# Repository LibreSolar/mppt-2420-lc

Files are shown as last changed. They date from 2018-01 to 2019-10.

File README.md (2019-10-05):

# MPPT Charger 20A

 Outdated design, development of new revision ongoing.

**Important:** As we are currently developing a new revision of this charge controller with several improvements, it is not recommended to rebuild this device anymore. Please see [this forum thread](https://talk.libre.solar/t/community-development-of-new-20a-mppt/121) and feel free to contribute your ideas.

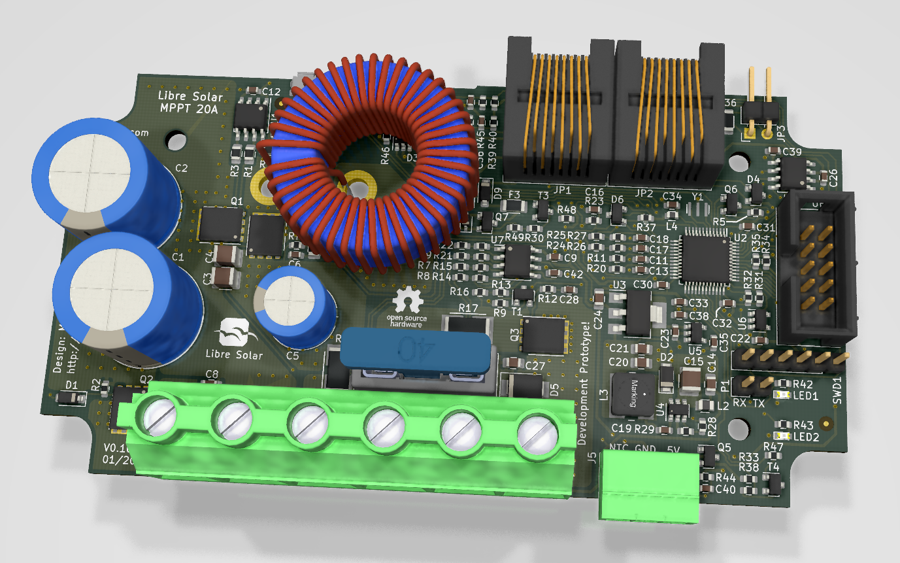
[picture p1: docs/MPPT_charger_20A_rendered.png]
Charge controller PCB


## Features:
- 20A MPPT charger (buck converter)
- 55V max PV input
- 12V or 24V battery output
- 32bit ARM MCU (STM32F072)
- CAN communication interface with CANopen standard RJ45 jacks (including 10V power supply)
- Expandable via Olimex Universal Extension Connector (UEXT) featuring I2C, Serial and SPI interface (e.g. used for display, WIFI communication, etc.)
- Compatible to Hammond Mfg 1591XXCFL housing
- 5V switchable signal output
- USB connector for programming etc.
- Can be used as boost converter with software change
- Suitable for Li-Ion batteries with BMS (even recharge after low voltage disconnect possible, as the charge controller increases the voltage automatically when enoug sunlight is available)

## Built-in protection:
- Overvoltage
- Undervoltage
- Overcurrent
- PV short circuit
- PV reverse polarity (for max. module open circuit voltage of around 40V)
- Battery reverse polarity (destructive, fuse is blown)

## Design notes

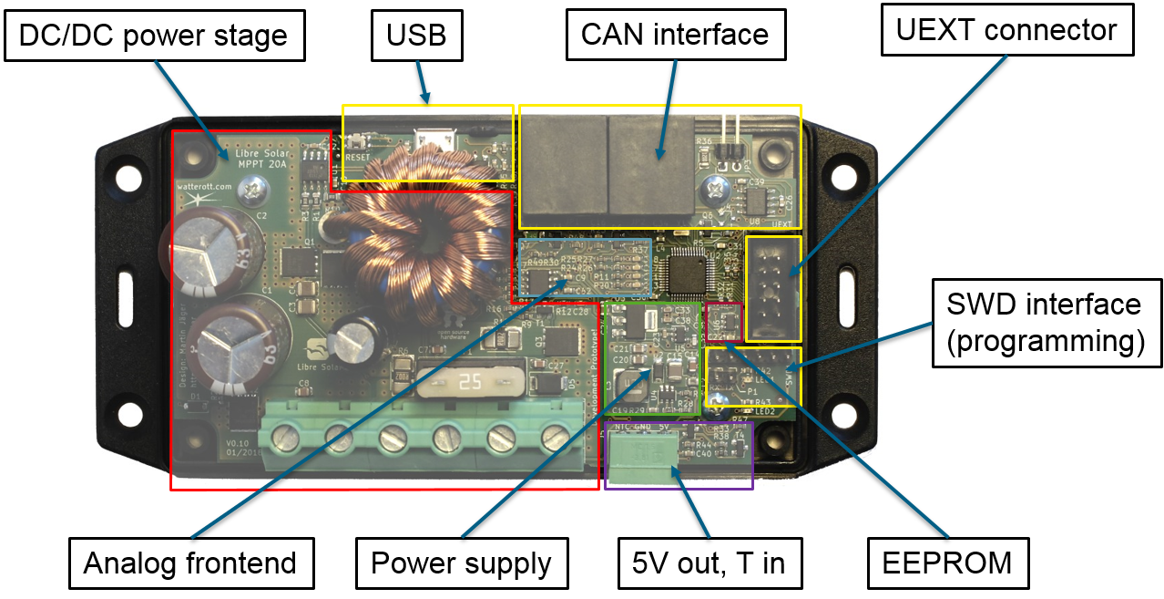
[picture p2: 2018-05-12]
docs/mppt_20a_hw_overview.png

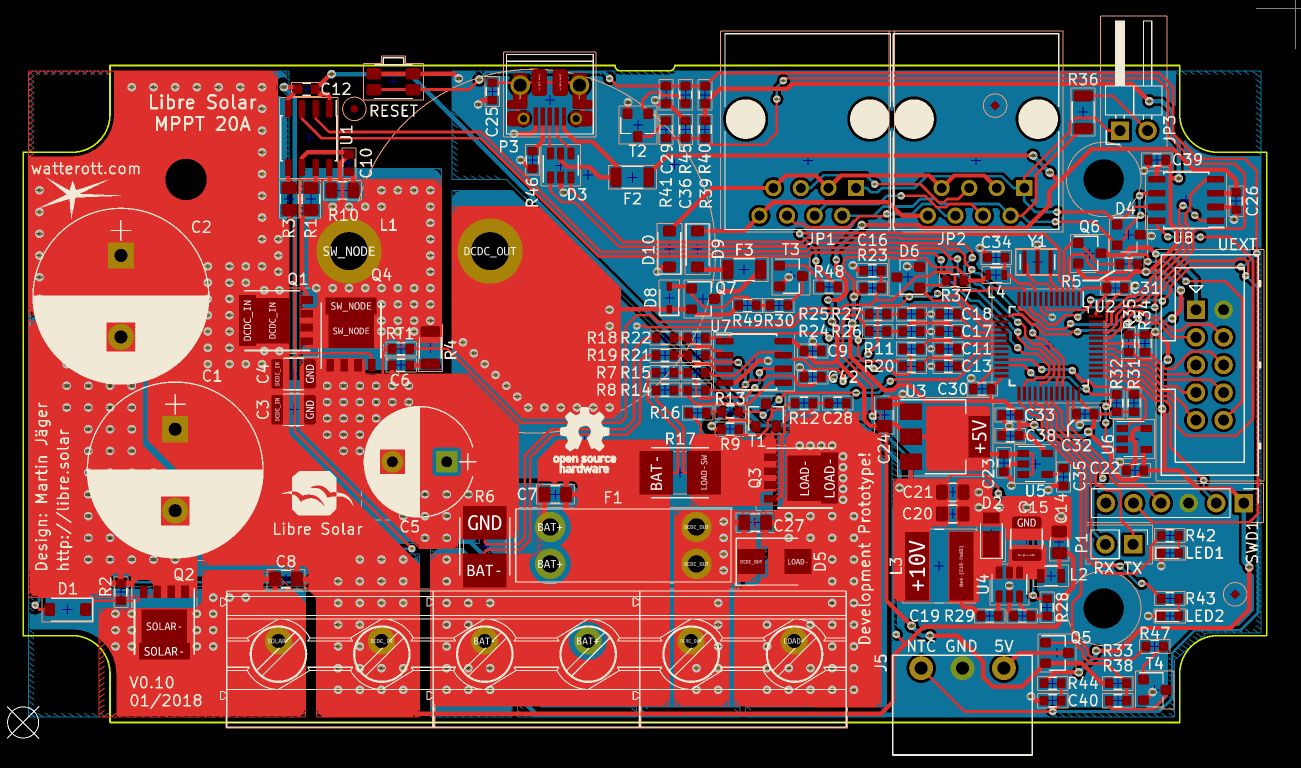
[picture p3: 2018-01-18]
docs/MPPT_charger_20A_top_view.png

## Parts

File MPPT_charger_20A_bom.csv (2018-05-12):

Component | Description | Part | References | Value | Footprint | Quantity Per PCB | Datasheet | Remarks | PartNumber | Manufacturer | Alternative | Supplier
1 | Polarised capacitor | CP_Small | C1 C2 | 1000u | CP_Radial_D16.0mm_P7.50mm | 2 |  | 63V, 2.74A, 16x25 | EKYB630ELL102ML25S | United Chemi-Con
2 | Unpolarized capacitor | C | C9 C10 C16 C19 C22 C25 C26 C29 C30 C31 C32 C34 C39 C40 C42 | 100n | C_0603_1608 | 15 |  |  | GRM188R71H104KA93D | Murata
3 | Unpolarized capacitor | C | C35 | 100p | C_0603_1608 | 1 |  |  | GRM1885C2A101JA01D | Murata
4 | Unpolarized capacitor | C | C11 C13 C17 C18 C28 | 10n | C_0603_1608 | 5 |  |  | GRM188R71H103KA01J | Murata
5 | Unpolarized capacitor | C | C20 C21 C24 | 10u | C_0805_2012 | 3 |  | 25V | GRM21BR61E106KA73L | Murata
6 | Unpolarized capacitor | C | C6 | 1n | C_0603_1608 | 1 |  | NP0/C0G | GRM1885C2A102JA01D | Murata
7 | Unpolarized capacitor | C | C7 C8 C14 C27 | 1u | C_0805_2012 | 4 |  | 100V, X7S | GRJ21BC72A105KE11L | Murata
8 | Unpolarized capacitor | C | C12 C23 C33 C36 C38 | 2.2u | C_0603_1608 | 5 |  | 25V, X5R | GRM188R61E225KA12D | Murata
9 | Unpolarized capacitor | C | C3 C4 C15 | 4.7u | C_1210_3225 | 3 |  | 100V, X7S | GRJ32DC72A475KE11L | Murata
10 | Polarised capacitor | CP_Small | C5 | 820u | CP_Radial_D10.0mm_P5.00mm | 1 |  | 35V, 2.47A | EEU-FR1V821L | Panasonic
11 | Diode | D | D1 D9 D10 | 1N4148 | D_SOD-123 | 3 |  |  | 1N4148W-7-F | Diodes Inc.
12 | Zener Diode, small symbol | D_Zener_Small | D6 | LM4040CYM3-2.5 | SOT-23 | 1 |  |  | LM4040DYM3-2.5-TR | Microchip
13 | Zener Diode, small symbol | D_Zener_Small | D8 | MM3Z12VT1G | D_SOD-323 | 1 |  |  | MM3Z12VT1G | ON Semiconductor
14 |  | NUP2105L | D4 | NUP2105L | SOT-23 | 1 |  |  | NUP2105LT1G | ON Semiconductor | SZNUP2105L
15 | Zener Diode, small symbol | D_Zener_Small | D5 | SMBJ36A | D_SMB | 1 | https://en.wikipedia.org/wiki/Zener_diode |  | SMBJ36A | Bourns
16 | Diode Schottky | D_Schottky | D2 | SS16FP | D_PowerDI-123 | 1 |  |  | SS16FP | Diodes Inc. | DFLS160-7
17 |  | USBLC6-2SC6 | D3 | USBLC6-2SC6Y | SOT-23-6 | 1 |  |  | USBLC6-2SC6Y | STMicroelectronics
18 | resettable fuse, polymeric positive temperature coefficient (PPTC) | Polyfuse | F2 F3 | 200mA | R_1206_3216 | 2 |  |  | 0ZCJ0020FF2E | Bel
19 | Fuse, small symbol | Fuse_Small | F1 | 25A | KEYSTONE-FUSE-3557-2 | 1 |  |  | 3557-2 | Keystone
20 |  | Screw_Terminal_1x02 | J3 | BAT | Phoenix_Contact_MKDS_5-2-952 | 1 |  |  | 1714971 | Phoenix Contact
21 | Generic connector, single row, 01x03, script generated (kicad-library-utils/schlib/autogen/connector/) | Conn_01x03 | J5 | CONN_01X03 | Phoenix_Contact_MC_1,5_3-G-3,81 | 1 |  |  | 1803280 | Phoenix Contact
22 |  | Screw_Terminal_1x02 | J2 | LOAD | Phoenix_Contact_MKDS_5-2-952 | 1 |  |  | 1714971 | Phoenix Contact
23 |  | Screw_Terminal_1x02 | J1 | SOLAR | Phoenix_Contact_MKDS_5-2-952 | 1 |  |  | 1714971 | Phoenix Contact
24 |  | UEXT | J4 | UEXT | Box_Header_2x05x2.54mm_Straight | 1
25 | Jumper, normally closed | Jumper_NC_Small | JP3 | Jumper_NC_Small | PinHeader_1x02_P2.54mm_Horizontal | 1
26 |  | RJ45_NS | JP1 JP2 | RJ45_NS | RJ45_8P8C | 2 |  |  | 54602-908LF | Amphenol FCI
27 | Inductor with Iron Core | L_Core_Iron | L1 | 22uH | L-FERYSTER-DTMSS-27 | 1 |  |  | DTMSS-27/0,022/30-H | Feryster |  | Feryster
28 | Inductor, small symbol | L_Small | L2 | 4.7uH | L_0805_2012Metric | 1 |  |  | LQM21PN4R7NGRD | Murata
29 | Inductor, small symbol | L_Small | L3 | 47uH | Bourns_SRN6045TA | 1 |  |  | NR6045T470M | Tayo Yuden | Bourns SRR6045TA-470Y
30 | Inductor, small symbol | L_Small | L4 | 600R | L_0603_1608Metric | 1 |  |  | BLM18AG601SN1D | Murata
31 |  | D_LED | LED2 | LED_green | LED_0603_1608Metric | 1 |  |  | LTST-C190GKT | Lite-On
32 |  | D_LED | LED1 | LED_red | LED_0603_1608Metric | 1 |  | red | LTST-C190KRKT | Lite-On
33 | Generic connector, single row, 01x02, script generated (kicad-library-utils/schlib/autogen/connector/) | Conn_01x02 | P1 | CONN_01X02 | PinHeader_1x02_P2.54mm_Vertical | 1
34 | USB Micro Type B connector | USB_B_Micro | P3 | USB Micro B | USB_Micro-B_10103594-0001LF | 1 |  |  | 10103594-0001LF | FCI |  | Mouser
35 | Transistor P-MOSFET with substrate diode (general) | Q_PMOS_GSD | Q5 Q6 Q7 | BSS84 | SOT-23 | 3 |  |  | BSS84 | Fairchild
36 | Transistor N-MOSFET (general) | Q_NMOS | Q1 Q2 Q3 Q4 | CSD18540Q5B | 5X6_MOSFET | 4 |  |  | CSD18540Q5BT | Texas Instruments
37 | Resistor | R | R5 R24 R25 R33 R46 R47 | 100k | R_0603_1608 | 6 |  |  | RC0603FR-07100KL | Yageo
38 | Resistor | R | R16 R23 R27 R29 R37 R44 R48 | 10k | R_0603_1608 | 7 |  |  | RC0603FR-0710KL | Yageo
39 | Resistor | R | R28 | 110k | R_0603_1608 | 1 |  |  | RC0603FR-07110KL | Yageo
40 | Resistor | R | R36 | 120 | R_1206_3216 | 1 |  |  | RC1206FR-07120RL | Yageo
41 | Resistor | R | R14 R15 R21 R22 | 150k | R_0603_1608 | 4 |  |  | RC0603FR-07150KL | Yageo
42 | Resistor | R | R2 R39 R40 R50 | 1M | R_0603_1608 | 4 |  |  | RC0603FR-071ML | Yageo
43 | Resistor | R | R4 | 2.2 | R_1206_3216 | 1 |  |  | RC1206FR-072R2L | Yageo
44 | Resistor | R | R7 R8 R11 R12 R13 R18 R19 R20 R31 R32 R34 R35 R38 R41 | 2.2k | R_0603_1608 | 14 |  |  | RC0603FR-072K2L | Yageo
45 | Resistor | R | R6 R17 | 2m | R_Bourns_CRE2512 | 2 |  |  | CRE2512-FZ-R002E-3 | Bourns
46 | Resistor | R | R1 R3 R10 | 3.3 | R_0805_2012 | 3 |  |  | RC0805FR-073R3L | Yageo
47 | Resistor | R | R42 R43 | 330 | R_0603_1608 | 2 |  |  | RC0603FR-07330RL | Yageo
48 | Resistor | R | R26 | 5.6k | R_0603_1608 | 1 |  |  | RC0603FR-075K6L | Yageo
49 | Resistor | R | R9 R30 R45 R49 | 56k | R_0603_1608 | 4 |  |  | RC0603FR-0756KL | Yageo
50 | temperature dependent resistor, negative temperature coefficient (NTC) | Thermistor_NTC | RT1 | 10k | R_0603_1608 | 1 |  |  | NTCG163JF103FT1S | TDK
51 | Push button switch, generic, two pins | SW_Push | SW1 | SW_PUSH | SW_SPST_EVQP7A | 1 |  |  | PTS840 GK SMTR LFS | C&K Components
52 |  | ST_Nucleo_SWD | SWD1 | ST_Nucleo_SWD | PinHeader_1x06_P2.54mm_Vertical | 1
53 | 0.8A Ic, 45V Vce, NPN Transistor, SOT-23 | BC817 | T1 T2 T3 T4 | MMBT3904 | SOT-23 | 4 | http://www.fairchildsemi.com/ds/BC/BC817.pdf |  | MMBT3904-7-F | Diodes Inc.
54 | Microchip 24AA01 1K I2C EEPROM | 24AA01 | U6 | 24AA01 | SOT-23-5 | 1 |  |  | 24AA32AFT-I/OT | Microchip
55 | 300mA low dropout linear regulator, shutdown pin, 1.5V fixed positive output, SOT-23-5 package | AP2210-3.3 | U5 | AP2210-3.3 | SOT-23-5 | 1 | http://www.diodes.com/_files/datasheets/AP131.pdf |  | AP2210K-3.3TRG1 | Diodes Inc. | MIC5225
56 |  | AZ1117 | U3 | AZ1117 | SOT-223-3_TabPin2 | 1 |  |  | AZ1117EH-5.0TRG1 | Diodes Inc.
57 | Dual Opamp, SOIC-8/DIP-8/SSOP-8/TO-99 | Opamp_Dual_Generic | U7 | LM258 | SOIC-8_3.9x4.9mm_Pitch1.27mm | 1 |  |  | LM258DR | Texas Instruments
58 |  | LM5107 | U1 | LM5107 | SOIC-8_3.9x4.9mm_Pitch1.27mm | 1 |  |  | LM5107MAX/NOPB | Texas Instruments
59 | SIMPLE SWITCHER® 4V to 60V, 600mA Step-Down Regulator with Low Iq | LMR16006 | U4 | MP2459 | SOT-23-6 | 1 |  |  | MP2459GJ-Z | Monolithic Power | LMR16006XDDCR
60 |  | STM32F072CB | U2 | STM32F072CB | LQFP-48_7x7mm_P0.5mm | 1 |  |  | STM32F072CBT6 | STMicroelectronics
61 | TJA1042T/3, High-Speed CAN Transceiver, separate VIO, standby mode, SOIC-8 | TJA1042T-3 | U8 | TJA1042T/3 | SOIC-8_3.9x4.9mm_Pitch1.27mm | 1 | http://www.nxp.com/documents/data_sheet/TJA1042.pdf |  | TJA1042T/3/1J | NXP |  | Mouser
62 | Three pin ceramic resonator | Resonator_Small | Y1 | 8MHz | Resonator_Murata_CSTCE_G | 1 |  | 0.1% tolerance | CSTCE8M00G15C99-R0 | Murata
Component Groups: | 62
Component Count: | 141
Fitted Components: | 141
Number of PCBs: | 1
Total components: | 141
Schematic Version: | 0.10
Schematic Date: | 2018-01-18
BoM Date: | 12/05/2018 20:13:11
Schematic Source: | D:\LibreSolar\2_Development\04_Hardware\MPPT-Charger_20A\MPPT_charger_20A.sch
KiCad Version: | Eeschema (5.0.0-rc2-dev-444-g2974a2c10)

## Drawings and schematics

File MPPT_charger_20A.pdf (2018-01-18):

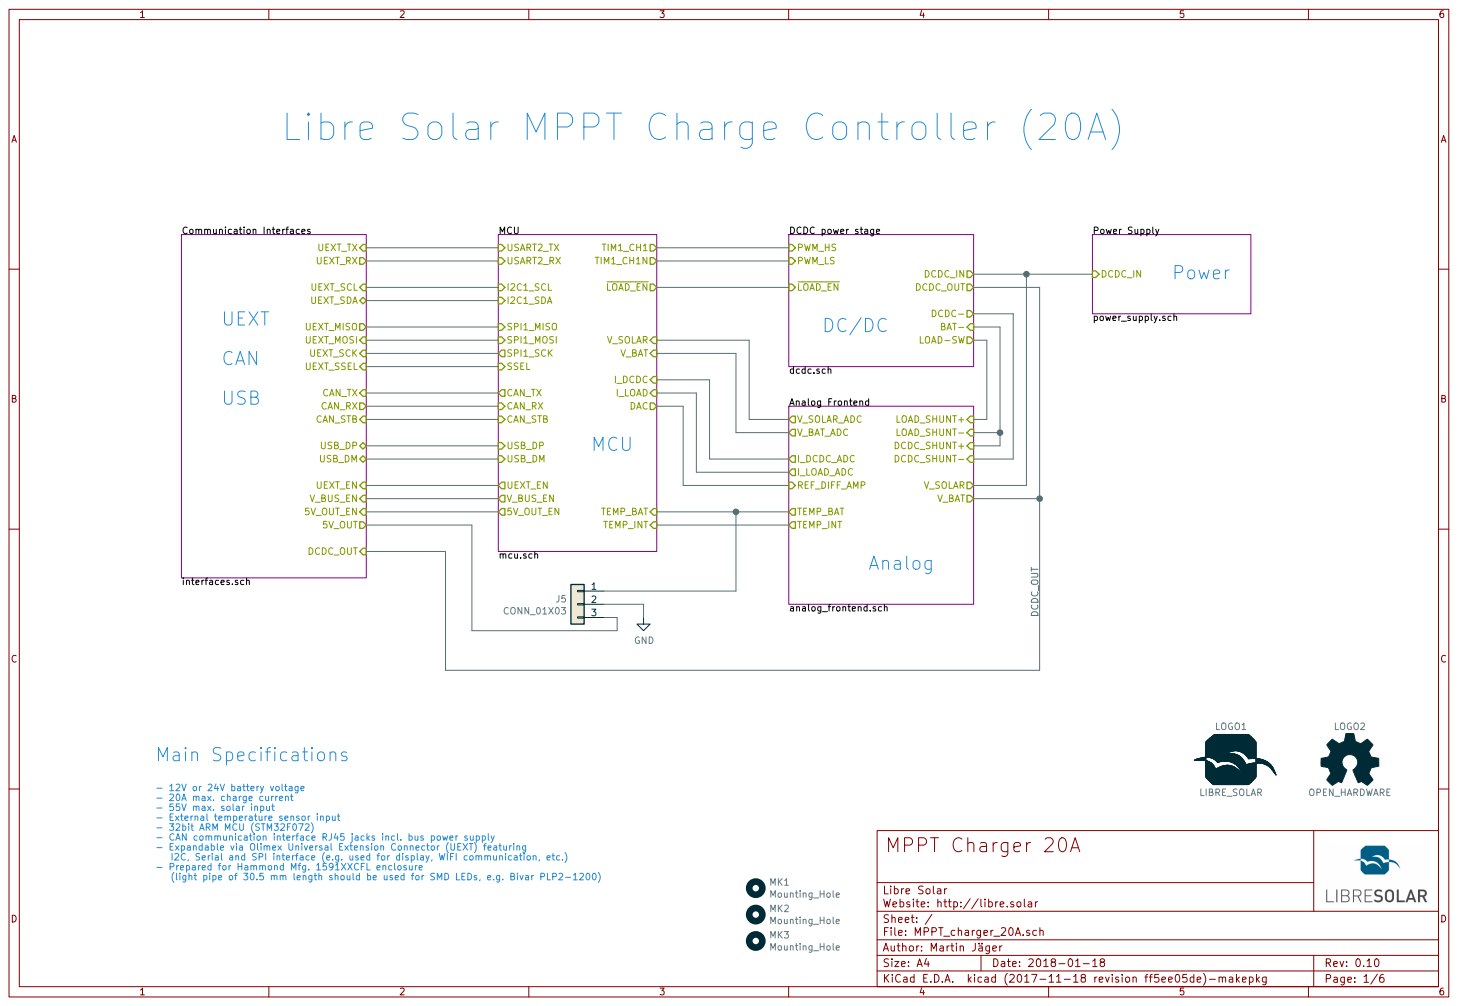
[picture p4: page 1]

V_BUS_EN Libre Solar MPPT Charge Controller (20A)

- 12V or 24V battery voltage
- 20A max. charge current
- 55V max. solar input
- External temperature sensor input
- 32bit ARM MCU (STM32F072)
- CAN communication interface RJ45 jacks incl. bus power supply
- Expandable via Olimex Universal Extension Connector (UEXT) featuring
I2C, Serial and SPI interface (e.g. used for display, WIFI communication, etc.)
- Prepared for Hammond Mfg. 1591XXCFL enclosure

File: MPPT_charger_20A.sch Sheet: / Libre Solar Author: Martin Jäger
Website: http://libre.solar

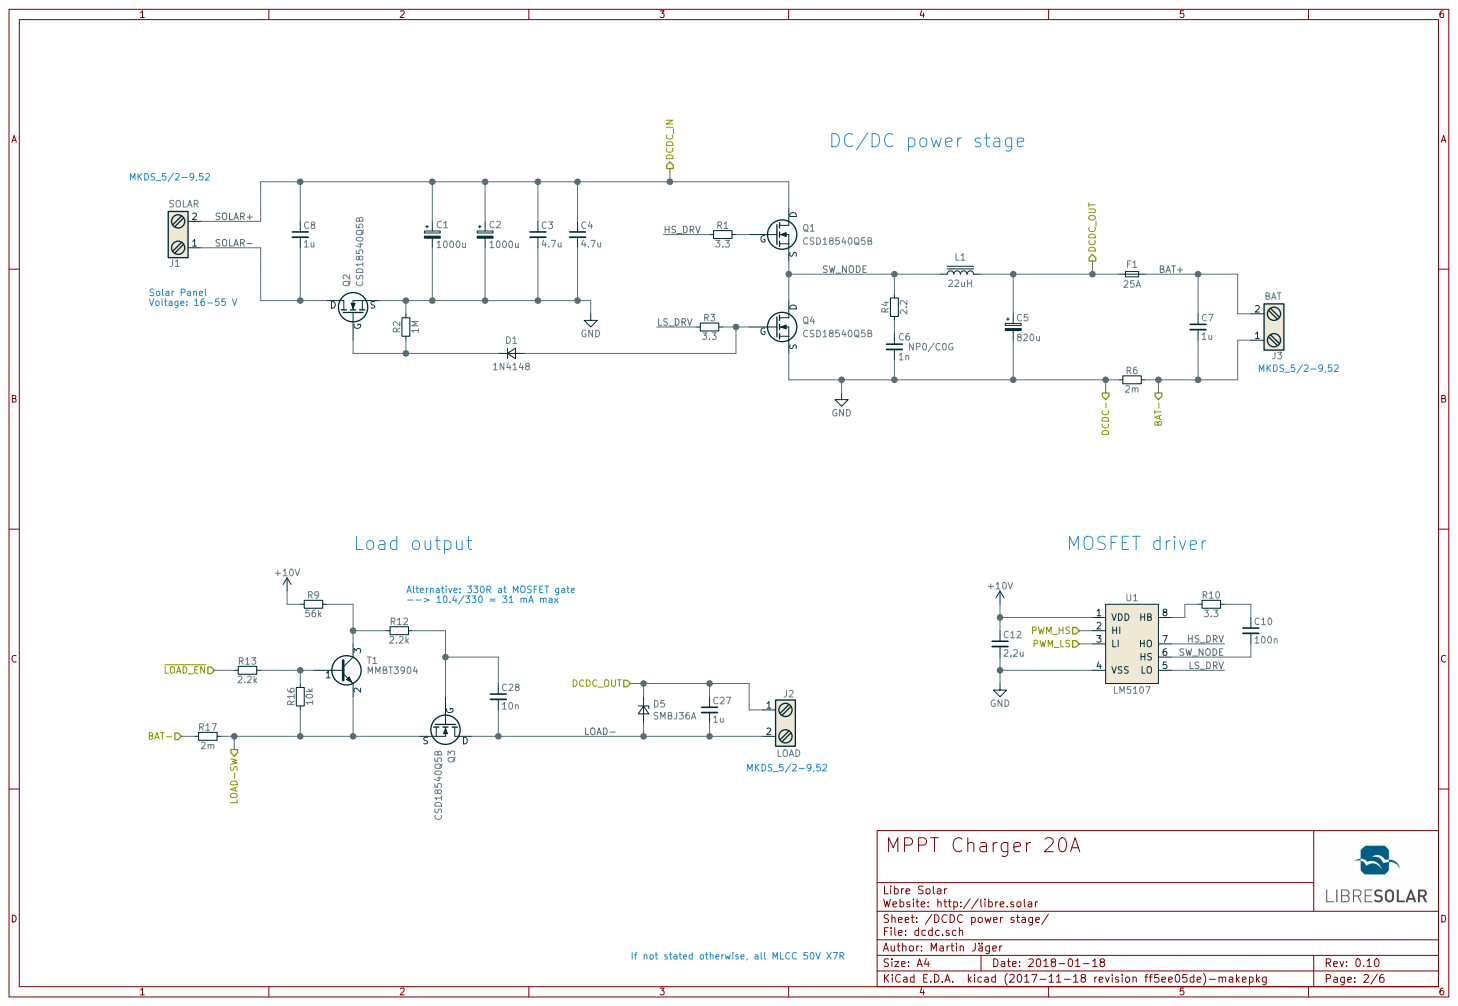
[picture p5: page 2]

DC/DC power stage

Website: http://libre.solar GND GND

Alternative: 330R at MOSFET gate
--> 10.4/330 = 31 mA max

File: dcdc.sch Sheet: /DCDC power stage/ Libre Solar Author: Martin Jäger

If not stated otherwise, all MLCC 50V X7R

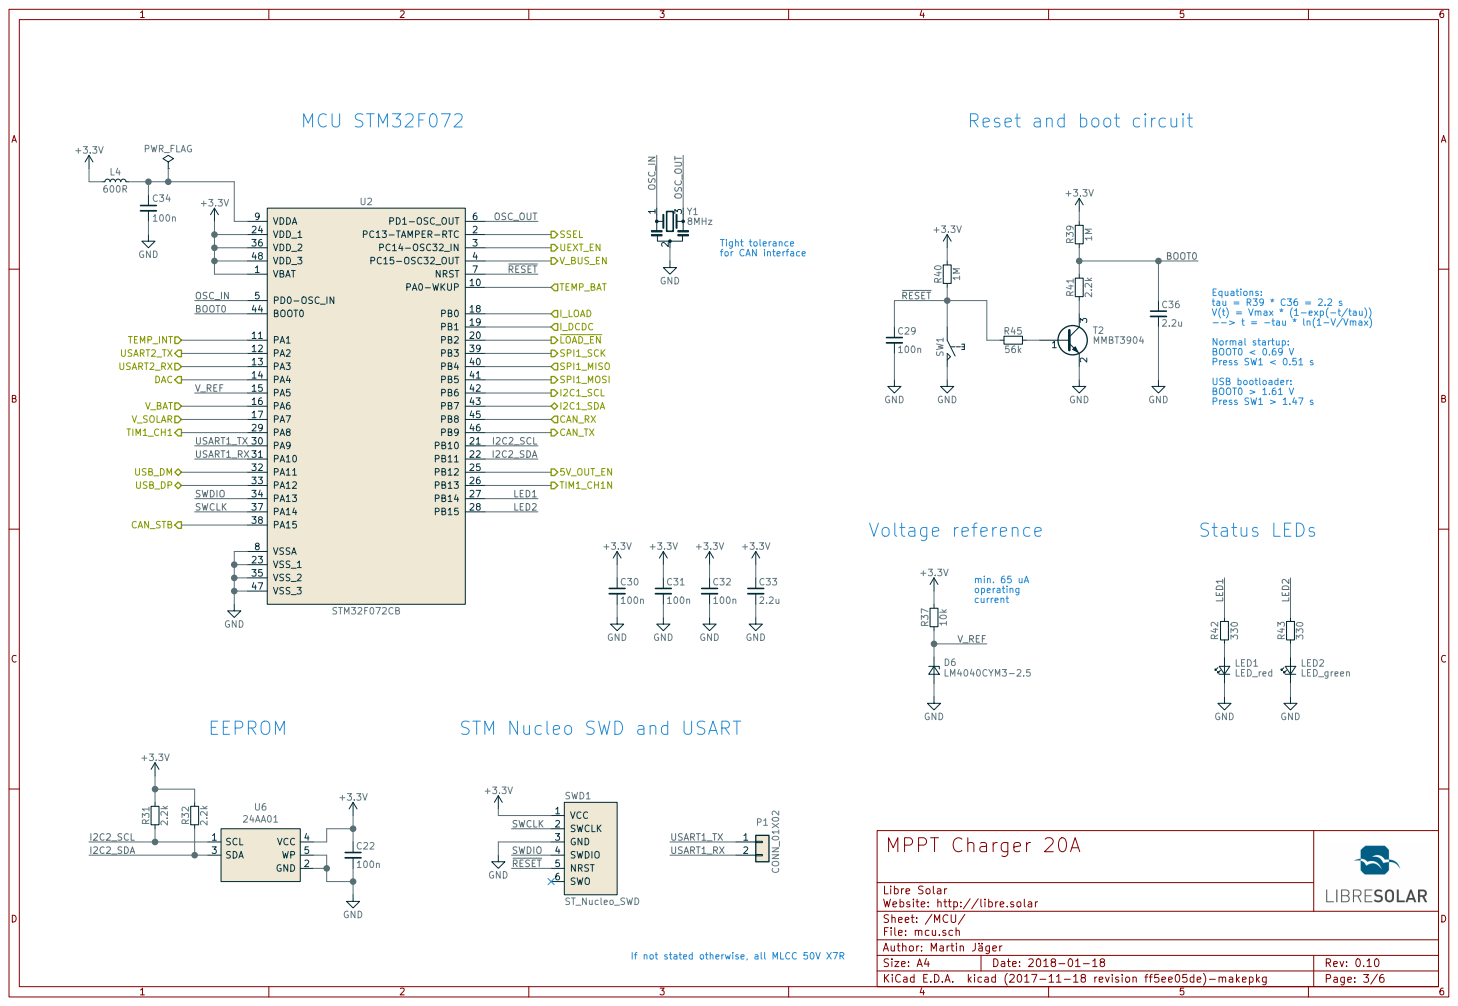
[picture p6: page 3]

Reset and boot circuit

tau = R39 * C36 = 2.2 s V(t) = Vmax * (1-exp(-t/tau))
--> t = -tau * ln(1-V/Vmax)
Normal startup: BOOT0 < 0.69 V
Press SW1 < 0.51 s USB bootloader: BOOT0 > 1.61 V

5V_OUT_EN
Website: http://libre.solar D6

STM Nucleo SWD and USART

File: mcu.sch Sheet: /MCU/ Libre Solar Author: Martin Jäger

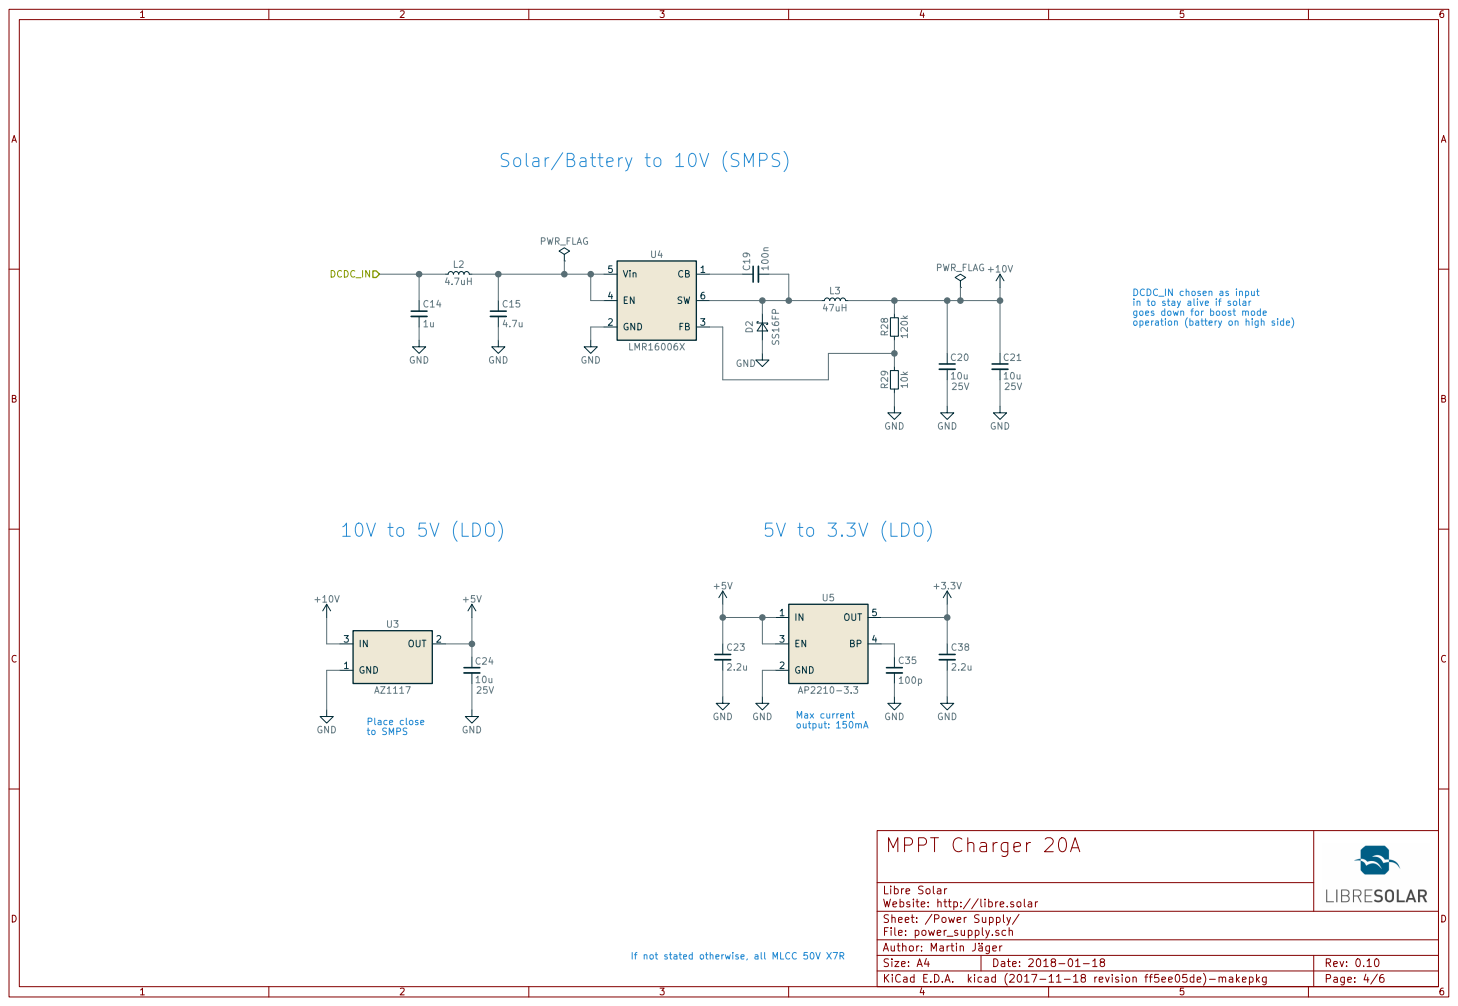
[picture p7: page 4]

DCDC_IN chosen as input
in to stay alive if solar
goes down for boost mode

operation (battery on high side) +10V

to SMPS 10V to 5V (LDO)

Sheet: /Power Supply/ Libre Solar Author: Martin Jäger

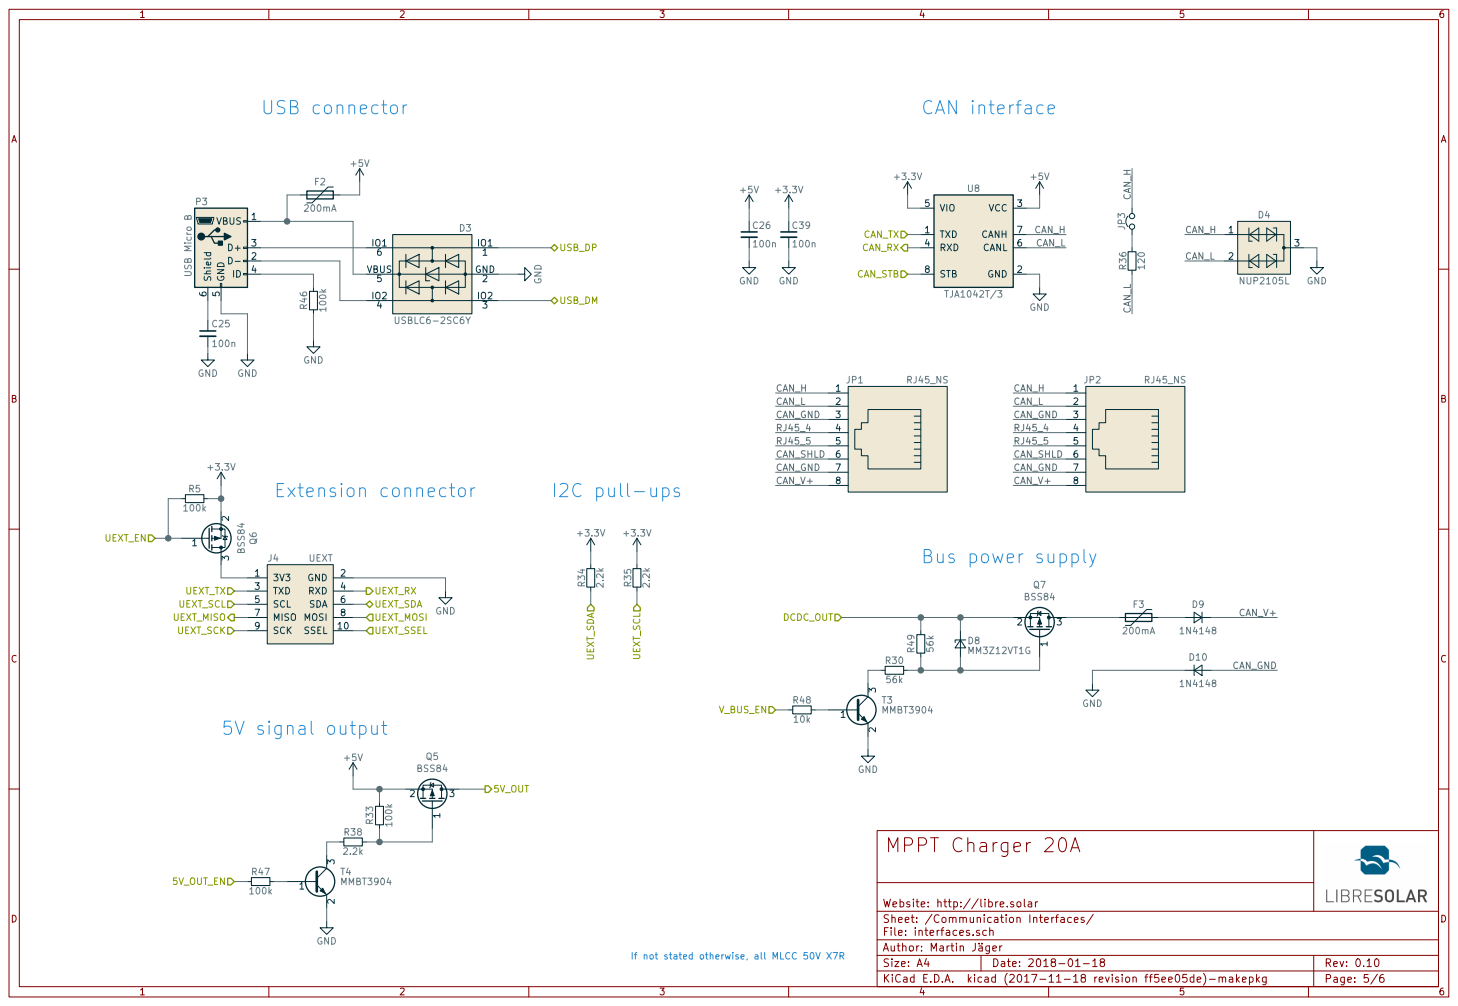
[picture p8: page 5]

Website: http://libre.solar
File: interfaces.sch Sheet: /Communication Interfaces/ Author: Martin Jäger

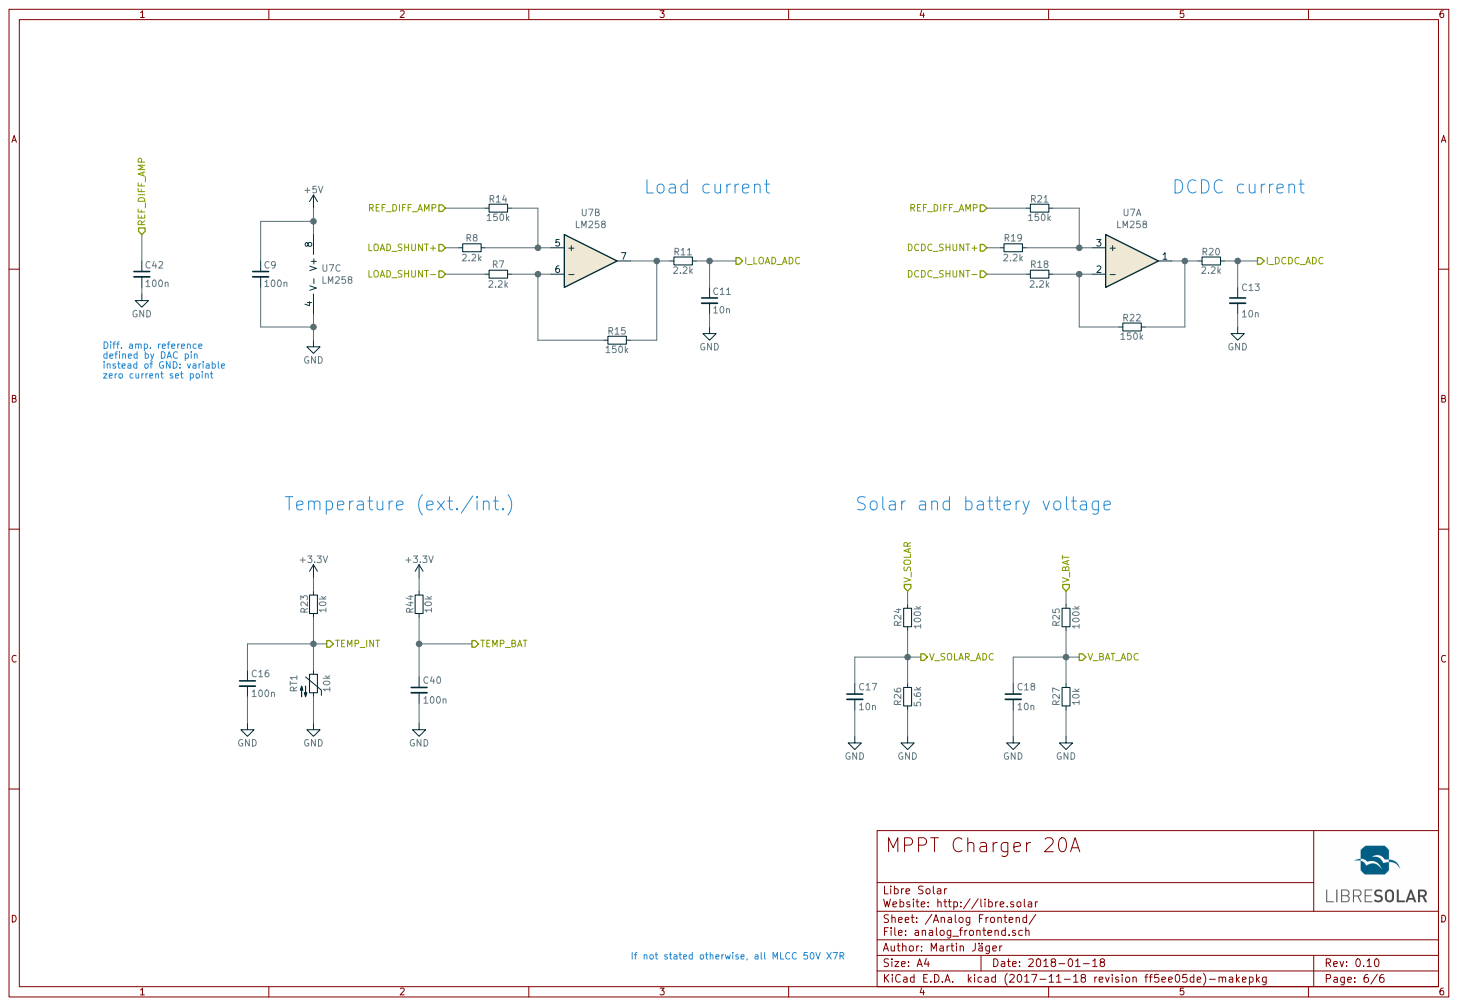
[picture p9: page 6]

Diff. amp. reference
defined by DAC pin
instead of GND: variable
zero current set point

Solar and battery voltage

Sheet: /Analog Frontend/ Libre Solar Author: Martin Jäger

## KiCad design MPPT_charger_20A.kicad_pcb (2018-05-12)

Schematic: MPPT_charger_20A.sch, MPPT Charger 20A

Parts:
J5: CONN_01X03; Phoenix_Contact_MC_1,5_3-G-3,81; PartNumber 1803280
LOGO1: LIBRE_SOLAR; LIBRESOLAR_LOGO
LOGO2: OPEN_HARDWARE; OSHW-Logo_5.7x6mm_SilkScreen
MK1, MK2, MK3: Mounting_Hole; MountingHole_3.2mm_M3

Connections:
/Analog Frontend/TEMP_BAT: J5.1; also elsewhere on the board
/Communication Interfaces/5V_OUT: J5.3; also elsewhere on the board
GND: J5.2; also elsewhere on the board

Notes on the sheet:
Libre Solar MPPT Charge Controller (20A)
Main Specifications
- 12V or 24V battery voltage - 20A max. charge current - 55V max. solar input - External temperature sensor input - 32bit ARM MCU (STM32F072) - CAN communication interface RJ45 jacks incl. bus power supply - Expandable via Olimex Universal Extension Connector (UEXT) featuring I2C, Serial and SPI in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
UEXT CAN USB
DC/DC
MCU
Analog
Power

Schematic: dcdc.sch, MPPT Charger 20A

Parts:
C1, C2: 1000u; CP_Radial_D16.0mm_P7.50mm; PartNumber EKYB630ELL102ML25S
C3, C4: 4.7u; C_1210_3225; PartNumber GRJ32DC72A475KE11L
C5: 820u; CP_Radial_D10.0mm_P5.00mm; PartNumber EEU-FR1V821L
C6: 1n; C_0603_1608; PartNumber GRM1885C2A102JA01D
C7, C8, C27: 1u; C_0805_2012; PartNumber GRJ21BC72A105KE11L
C10: 100n; C_0603_1608; PartNumber GRM188R71H104KA93D
C12: 2.2u; C_0603_1608; PartNumber GRM188R61E225KA12D
C28: 10n; C_0603_1608; PartNumber GRM188R71H103KA01J
D1: 1N4148; D_SOD-123; PartNumber 1N4148W-7-F
D5: SMBJ36A; D_SMB; PartNumber SMBJ36A
F1: 25A; KEYSTONE-FUSE-3557-2; PartNumber 3557-2
J1: SOLAR; Phoenix_Contact_MKDS_5-2-952; PartNumber 1714971
J2: LOAD; Phoenix_Contact_MKDS_5-2-952; PartNumber 1714971
J3: BAT; Phoenix_Contact_MKDS_5-2-952; PartNumber 1714971
L1: 22uH; L-FERYSTER-DTMSS-27; PartNumber DTMSS-27/0,022/30-H
Q1, Q2, Q3, Q4: CSD18540Q5B; 5X6_MOSFET; PartNumber CSD18540Q5BT
R1, R3, R10: 3.3; R_0805_2012; PartNumber RC0805FR-073R3L
R2: 1M; R_0603_1608; PartNumber RC0603FR-071ML
R4: 2.2; R_1206_3216; PartNumber RC1206FR-072R2L
R6, R17: 2m; R_Bourns_CRE2512; PartNumber CRE2512-FZ-R002E-3
R9: 56k; R_0603_1608; PartNumber RC0603FR-0756KL
R12, R13: 2.2k; R_0603_1608; PartNumber RC0603FR-072K2L
R16: 10k; R_0603_1608; PartNumber RC0603FR-0710KL
T1: MMBT3904; SOT-23; PartNumber MMBT3904-7-F
U1: LM5107; SOIC-8_3.9x4.9mm_Pitch1.27mm; PartNumber LM5107MAX/NOPB

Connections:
+10V: C12.1, R9.2, U1.1 (VDD); also elsewhere on the board
/DCDC power stage/BAT+: C7.1, F1.2, J3.2
/DCDC power stage/BAT-: C7.2, J3.1, R6.2, R17.1; also elsewhere on the board
/DCDC power stage/DCDC_IN: C1.1, C2.1, C3.1, C4.1, C8.1, J1.2, Q1.D; also elsewhere on the board
/DCDC power stage/HS_DRV: R1.2, U1.7 (HO)
/DCDC power stage/LOAD-: C27.2, C28.2, D5.2 (A), J2.2, Q3.D
/DCDC power stage/LOAD-SW: Q3.S, R16.1, R17.2, T1.2 (E); also elsewhere on the board
/DCDC power stage/LS_DRV: R3.2, U1.5 (LO)
/DCDC power stage/PWM_HS: U1.2 (HI); also elsewhere on the board
/DCDC power stage/PWM_LS: U1.3 (LI); also elsewhere on the board
/DCDC power stage/SOLAR-: C8.2, J1.1, Q2.D
/DCDC power stage/SW_NODE: C10.2, L1.1, Q1.S, Q4.D, R4.2, U1.6 (HS)
/DCDC power stage/~LOAD_EN: R13.2; also elsewhere on the board
/DCDC_OUT: C5.1, C27.1, D5.1 (K), F1.1, J2.1, L1.2; also elsewhere on the board
GND: C1.2, C2.2, C3.2, C4.2, C5.2, C6.2, C12.2, Q2.S, Q4.S, R2.1, R6.1, U1.4 (VSS); also elsewhere on the board
unnamed: C6.1, R4.1
unnamed: C10.1, R10.1
unnamed: C28.1, Q3.G, R12.1
unnamed: D1.1, Q2.G, R2.2
unnamed: D1.2, Q4.G, R3.1
unnamed: Q1.G, R1.1
unnamed: R10.2, U1.8 (HB)
unnamed: R9.1, R12.2, T1.3 (C)
unnamed: R13.1, R16.2, T1.1 (B)

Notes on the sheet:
Solar Panel Voltage: 16-55 V
DC/DC power stage
Load output
MOSFET driver
Alternative: 330R at MOSFET gate --> 10.4/330 = 31 mA max
If not stated otherwise, all MLCC 50V X7R
MKDS_5/2-9,52
typisch: 1-10 nF + 10 uF

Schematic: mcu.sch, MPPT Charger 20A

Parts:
C22, C29, C30, C31, C32, C34: 100n; C_0603_1608; PartNumber GRM188R71H104KA93D
C33, C36: 2.2u; C_0603_1608; PartNumber GRM188R61E225KA12D
D6: LM4040CYM3-2.5; SOT-23; PartNumber LM4040DYM3-2.5-TR
L4: 600R; L_0603_1608Metric; PartNumber BLM18AG601SN1D
LED1: LED_red; LED_0603_1608Metric; PartNumber LTST-C190KRKT
LED2: LED_green; LED_0603_1608Metric; PartNumber LTST-C190GKT
P1: CONN_01X02; PinHeader_1x02_P2.54mm_Vertical
R31, R32, R41: 2.2k; R_0603_1608; PartNumber RC0603FR-072K2L
R37: 10k; R_0603_1608; PartNumber RC0603FR-0710KL
R39, R40: 1M; R_0603_1608; PartNumber RC0603FR-071ML
R42, R43: 330; R_0603_1608; PartNumber RC0603FR-07330RL
R45: 56k; R_0603_1608; PartNumber RC0603FR-0756KL
SW1: SW_PUSH; SW_SPST_EVQP7A; PartNumber PTS840 GK SMTR LFS
SWD1: ST_Nucleo_SWD; PinHeader_1x06_P2.54mm_Vertical
T2: MMBT3904; SOT-23; PartNumber MMBT3904-7-F
U2: STM32F072CB; LQFP-48_7x7mm_P0.5mm; PartNumber STM32F072CBT6
U6: 24AA01; SOT-23-5; PartNumber 24AA32AFT-I/OT
Y1: 8MHz; Resonator_Murata_CSTCE_G; PartNumber CSTCE8M00G15C99-R0

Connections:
+3V3: C22.1, C30.1, C31.1, C32.1, C33.1, L4.1, R31.2, R32.2, R37.2, R39.2, R40.2, SWD1.1 (VCC), U2.1 (VBAT), U2.24 (VDD_1), U2.36 (VDD_2), U2.48 (VDD_3), U6.4 (VCC); also elsewhere on the board
/Analog Frontend/TEMP_BAT: U2.10 (PA0-WKUP); also elsewhere on the board
/Analog Frontend/TEMP_INT: U2.11 (PA1); also elsewhere on the board
/Communication Interfaces/5V_OUT_EN: U2.25 (PB12); also elsewhere on the board
/Communication Interfaces/CAN_RX: U2.45 (PB8); also elsewhere on the board
/Communication Interfaces/CAN_STB: U2.38 (PA15); also elsewhere on the board
/Communication Interfaces/CAN_TX: U2.46 (PB9); also elsewhere on the board
/Communication Interfaces/UEXT_EN: U2.3 (PC14-OSC32_IN); also elsewhere on the board
/Communication Interfaces/UEXT_RX: U2.13 (PA3); also elsewhere on the board
/Communication Interfaces/UEXT_TX: U2.12 (PA2); also elsewhere on the board
/Communication Interfaces/USB_DM: U2.32 (PA11); also elsewhere on the board
/Communication Interfaces/USB_DP: U2.33 (PA12); also elsewhere on the board
/Communication Interfaces/V_BUS_EN: U2.4 (PC15-OSC32_OUT); also elsewhere on the board
/DCDC power stage/PWM_HS: U2.29 (PA8); also elsewhere on the board
/DCDC power stage/PWM_LS: U2.26 (PB13); also elsewhere on the board
/DCDC power stage/~LOAD_EN: U2.20 (PB2); also elsewhere on the board
/MCU/BOOT0: C36.1, R39.1, R41.2, U2.44 (BOOT0)
/MCU/DAC: U2.14 (PA4); also elsewhere on the board
/MCU/I2C1_SCL: U2.42 (PB6); also elsewhere on the board
/MCU/I2C1_SDA: U2.43 (PB7); also elsewhere on the board
/MCU/I2C2_SCL: R31.1, U2.21 (PB10), U6.1 (SCL)
/MCU/I2C2_SDA: R32.1, U2.22 (PB11), U6.3 (SDA)
/MCU/I_DCDC: U2.19 (PB1); also elsewhere on the board
/MCU/I_LOAD: U2.18 (PB0); also elsewhere on the board
/MCU/LED1: R42.2, U2.27 (PB14)
/MCU/LED2: R43.2, U2.28 (PB15)
/MCU/OSC_IN: U2.5 (PD0-OSC_IN), Y1.1
/MCU/OSC_OUT: U2.6 (PD1-OSC_OUT), Y1.3
/MCU/SPI1_MISO: U2.40 (PB4); also elsewhere on the board
/MCU/SPI1_MOSI: U2.41 (PB5); also elsewhere on the board
/MCU/SPI1_SCK: U2.39 (PB3); also elsewhere on the board
/MCU/SSEL: U2.2 (PC13-TAMPER-RTC); also elsewhere on the board
/MCU/SWCLK: SWD1.2 (SWCLK), U2.37 (PA14)
/MCU/SWDIO: SWD1.4 (SWDIO), U2.34 (PA13)
/MCU/USART1_RX: P1.2, U2.31 (PA10)
/MCU/USART1_TX: P1.1, U2.30 (PA9)
/MCU/V_BAT: U2.16 (PA6); also elsewhere on the board
/MCU/V_REF: D6.1 (K), R37.1, U2.15 (PA5)
/MCU/V_SOLAR: U2.17 (PA7); also elsewhere on the board
/MCU/~RESET: C29.1, R40.1, R45.1, SW1.1, SWD1.5 (NRST), U2.7 (NRST)
GND: C22.2, C29.2, C30.2, C31.2, C32.2, C33.2, C34.2, C36.2, D6.2 (A), LED1.1, LED2.1, SW1.2, SWD1.3 (GND), T2.2 (E), U2.8 (VSSA), U2.23 (VSS_1), U2.35 (VSS_2), U2.47 (VSS_3), U6.2 (GND), U6.5 (WP), Y1.2; also elsewhere on the board
unnamed: C34.1, L4.2, U2.9 (VDDA)
unnamed: LED1.2, R42.1
unnamed: LED2.2, R43.1
unnamed: R41.1, T2.3 (C)
unnamed: R45.2, T2.1 (B)

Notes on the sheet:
Status LEDs
MCU STM32F072
STM Nucleo SWD and USART
min. 65 uA operating current
Voltage reference
Reset and boot circuit
Tight tolerance for CAN interface
Equations: tau = R39 * C36 = 2.2 s V(t) = Vmax * (1-exp(-t/tau)) --> t = -tau * ln(1-V/Vmax) Normal startup: BOOT0 < 0.69 V Press SW1 < 0.51 s USB bootloader: BOOT0 > 1.61 V Press SW1 > 1.47 s
EEPROM
If not stated otherwise, all MLCC 50V X7R

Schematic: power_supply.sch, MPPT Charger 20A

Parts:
C14: 1u; C_0805_2012; PartNumber GRJ21BC72A105KE11L
C15: 4.7u; C_1210_3225; PartNumber GRJ32DC72A475KE11L
C19: 100n; C_0603_1608; PartNumber GRM188R71H104KA93D
C20, C21, C24: 10u; C_0805_2012; PartNumber GRM21BR61E106KA73L
C23, C38: 2.2u; C_0603_1608; PartNumber GRM188R61E225KA12D
C35: 100p; C_0603_1608; PartNumber GRM1885C2A101JA01D
D2: SS16FP; D_PowerDI-123; PartNumber SS16FP
L2: 4.7uH; L_0805_2012Metric; PartNumber LQM21PN4R7NGRD
L3: 47uH; Bourns_SRN6045TA; PartNumber NR6045T470M
R28: 110k; R_0603_1608; PartNumber RC0603FR-07110KL
R29: 10k; R_0603_1608; PartNumber RC0603FR-0710KL
R50: 1M; R_0603_1608; PartNumber RC0603FR-071ML
U3: AZ1117; SOT-223-3_TabPin2; PartNumber AZ1117EH-5.0TRG1
U4: MP2459; SOT-23-6; PartNumber MP2459GJ-Z
U5: AP2210-3.3; SOT-23-5; PartNumber AP2210K-3.3TRG1

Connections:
+3V3: C38.1, U5.5 (OUT); also elsewhere on the board
+5V: C23.1, C24.1, U3.2 (OUT), U5.1 (IN), U5.3 (EN); also elsewhere on the board
+10V: C20.1, C21.1, L3.2, R28.1, U3.3 (IN); also elsewhere on the board
/DCDC power stage/DCDC_IN: C14.1, L2.1; also elsewhere on the board
GND: C14.2, C15.2, C20.2, C21.2, C23.2, C24.2, C35.2, C38.2, D2.2, R29.2, U3.1 (GND), U4.2 (GND), U5.2 (GND); also elsewhere on the board
unnamed: C15.1, L2.2, R50.2, U4.5 (Vin)
unnamed: C19.1, U4.1 (CB)
unnamed: C19.2, D2.1, L3.1, U4.6 (SW)
unnamed: C35.1, U5.4 (BP)
unnamed: R28.2, R29.1, U4.3 (FB)
unnamed: R50.1, U4.4 (EN)

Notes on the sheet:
Max current output: 150mA
Solar/Battery to 10V (SMPS)
5V to 3.3V (LDO)
Place close to SMPS
10V to 5V (LDO)
Advantages of DCDC_IN as input: - Power supply possible through solar or battery (via HS MOSFET body diode) - Discharged Li-ion batteries (with enabled cut-off switch) can be recharged
If not stated otherwise, all MLCC 50V X7R
MP2459: R50 necessary to limit current into EN to <100uA R28 selection: 110k for MP2459 (9.7 V) 120k for LMR16006X (10 V)

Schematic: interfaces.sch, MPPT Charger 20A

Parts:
C25, C26, C39: 100n; C_0603_1608; PartNumber GRM188R71H104KA93D
D3: USBLC6-2SC6Y; SOT-23-6; PartNumber USBLC6-2SC6Y
D4: NUP2105L; SOT-23; PartNumber NUP2105LT1G
D8: MM3Z12VT1G; D_SOD-323; PartNumber MM3Z12VT1G
D9, D10: 1N4148; D_SOD-123; PartNumber 1N4148W-7-F
F2, F3: 200mA; R_1206_3216; PartNumber 0ZCJ0020FF2E
J4: UEXT; Box_Header_2x05x2.54mm_Straight
JP1, JP2: RJ45_NS; RJ45_8P8C; PartNumber 54602-908LF
JP3: Jumper_NC_Small; PinHeader_1x02_P2.54mm_Horizontal
P3: USB Micro B; USB_Micro-B_10103594-0001LF; PartNumber 10103594-0001LF
Q5, Q6, Q7: BSS84; SOT-23; PartNumber BSS84
R5, R33, R46, R47: 100k; R_0603_1608; PartNumber RC0603FR-07100KL
R30, R49: 56k; R_0603_1608; PartNumber RC0603FR-0756KL
R34, R35, R38: 2.2k; R_0603_1608; PartNumber RC0603FR-072K2L
R36: 120; R_1206_3216; PartNumber RC1206FR-07120RL
R48: 10k; R_0603_1608; PartNumber RC0603FR-0710KL
T3, T4: MMBT3904; SOT-23; PartNumber MMBT3904-7-F
U8: TJA1042T/3; SOIC-8_3.9x4.9mm_Pitch1.27mm; PartNumber TJA1042T/3/1J

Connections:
+3V3: C39.1, Q6.2 (S), R5.1, R34.2, R35.2, U8.5 (VIO); also elsewhere on the board
+5V: C26.1, F2.1, Q5.2 (S), R33.1, U8.3 (VCC); also elsewhere on the board
/Communication Interfaces/5V_OUT: Q5.3 (D); also elsewhere on the board
/Communication Interfaces/5V_OUT_EN: R47.2; also elsewhere on the board
/Communication Interfaces/CAN_GND: D10.2, JP1.3, JP1.7, JP2.3, JP2.7
/Communication Interfaces/CAN_H: D4.1, JP1.1, JP2.1, JP3.1, U8.7 (CANH)
/Communication Interfaces/CAN_L: D4.2, JP1.2, JP2.2, R36.2, U8.6 (CANL)
/Communication Interfaces/CAN_RX: U8.4 (RXD); also elsewhere on the board
/Communication Interfaces/CAN_SHLD: JP1.6, JP2.6
/Communication Interfaces/CAN_STB: U8.8 (STB); also elsewhere on the board
/Communication Interfaces/CAN_TX: U8.1 (TXD); also elsewhere on the board
/Communication Interfaces/CAN_V+: D9.1, JP1.8, JP2.8
/Communication Interfaces/RJ45_4: JP1.4, JP2.4
/Communication Interfaces/RJ45_5: JP1.5, JP2.5
/Communication Interfaces/UEXT_EN: Q6.1 (G), R5.2; also elsewhere on the board
/Communication Interfaces/UEXT_RX: J4.4 (RXD); also elsewhere on the board
/Communication Interfaces/UEXT_TX: J4.3 (TXD); also elsewhere on the board
/Communication Interfaces/USB_DM: D3.3 (IO2); also elsewhere on the board
/Communication Interfaces/USB_DP: D3.1 (IO1); also elsewhere on the board
/Communication Interfaces/V_BUS_EN: R48.2; also elsewhere on the board
/DCDC_OUT: D8.1 (K), Q7.2 (S), R49.1; also elsewhere on the board
/MCU/I2C1_SCL: J4.5 (SCL), R35.1; also elsewhere on the board
/MCU/I2C1_SDA: J4.6 (SDA), R34.1; also elsewhere on the board
/MCU/SPI1_MISO: J4.7 (MISO); also elsewhere on the board
/MCU/SPI1_MOSI: J4.8 (MOSI); also elsewhere on the board
/MCU/SPI1_SCK: J4.9 (SCK); also elsewhere on the board
/MCU/SSEL: J4.10 (SSEL); also elsewhere on the board
GND: C25.2, C26.2, C39.2, D3.2 (GND), D4.3, D10.1, J4.2 (GND), P3.5 (GND), R46.2, T3.2 (E), T4.2 (E), U8.2 (GND); also elsewhere on the board
unnamed: C25.1, P3.6 (Shield)
unnamed: D3.4 (IO2), P3.2 (D-)
unnamed: D3.5 (VBUS), F2.2, P3.1 (VBUS)
unnamed: D3.6 (IO1), P3.3 (D+)
unnamed: D8.2 (A), Q7.1 (G), R30.1, R49.2
unnamed: D9.2, F3.1
unnamed: F3.2, Q7.3 (D)
unnamed: J4.1 (3V3), Q6.3 (D)
unnamed: JP3.2, R36.1
unnamed: P3.4 (ID), R46.1
unnamed: Q5.1 (G), R33.2, R38.1
unnamed: R30.2, T3.3 (C)
unnamed: R38.2, T4.3 (C)
unnamed: R47.1, T4.1 (B)
unnamed: R48.1, T3.1 (B)

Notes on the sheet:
CAN interface
Extension connector
I2C pull-ups
USB connector
5V signal output
ToDo: check R47 --> should be smaller?
Bus power supply
If not stated otherwise, all MLCC 50V X7R

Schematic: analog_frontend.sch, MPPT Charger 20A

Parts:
C9, C16, C40, C42: 100n; C_0603_1608; PartNumber GRM188R71H104KA93D
C11, C13, C17, C18: 10n; C_0603_1608; PartNumber GRM188R71H103KA01J
R7, R8, R11, R18, R19, R20: 2.2k; R_0603_1608; PartNumber RC0603FR-072K2L
R14, R15, R21, R22: 150k; R_0603_1608; PartNumber RC0603FR-07150KL
R23, R27, R44: 10k; R_0603_1608; PartNumber RC0603FR-0710KL
R24, R25: 100k; R_0603_1608; PartNumber RC0603FR-07100KL
R26: 5.6k; R_0603_1608; PartNumber RC0603FR-075K6L
RT1: 10k; R_0603_1608; PartNumber NTCG163JF103FT1S
U7: LM258; SOIC-8_3.9x4.9mm_Pitch1.27mm; PartNumber LM258DR

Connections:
+3V3: R23.1, R44.1; also elsewhere on the board
+5V: C9.1, U7.8 (V+); also elsewhere on the board
/Analog Frontend/TEMP_BAT: C40.1, R44.2; also elsewhere on the board
/Analog Frontend/TEMP_INT: C16.1, R23.2, RT1.1; also elsewhere on the board
/DCDC power stage/BAT-: R7.2, R19.2; also elsewhere on the board
/DCDC power stage/DCDC_IN: R24.1; also elsewhere on the board
/DCDC power stage/LOAD-SW: R8.2; also elsewhere on the board
/DCDC_OUT: R25.1; also elsewhere on the board
/MCU/DAC: C42.1, R14.1, R21.2; also elsewhere on the board
/MCU/I_DCDC: C13.1, R20.2; also elsewhere on the board
/MCU/I_LOAD: C11.1, R11.2; also elsewhere on the board
/MCU/V_BAT: C18.1, R25.2, R27.1; also elsewhere on the board
/MCU/V_SOLAR: C17.1, R24.2, R26.1; also elsewhere on the board
GND: C9.2, C11.2, C13.2, C16.2, C17.2, C18.2, C40.2, C42.2, R18.2, R26.2, R27.2, RT1.2, U7.4 (V-); also elsewhere on the board
unnamed: R11.1, R15.2, U7.7
unnamed: R8.1, R14.2, U7.5 (+)
unnamed: R7.1, R15.1, U7.6 (-)
unnamed: R18.1, R22.1, U7.2 (-)
unnamed: R19.1, R21.1, U7.3 (+)
unnamed: R20.1, R22.2, U7.1

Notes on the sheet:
Load current
DCDC current
Solar and battery voltage
Diff. amp. reference defined by DAC pin instead of GND: variable zero current set point
If not stated otherwise, all MLCC 50V X7R
Temperature (ext./int.)

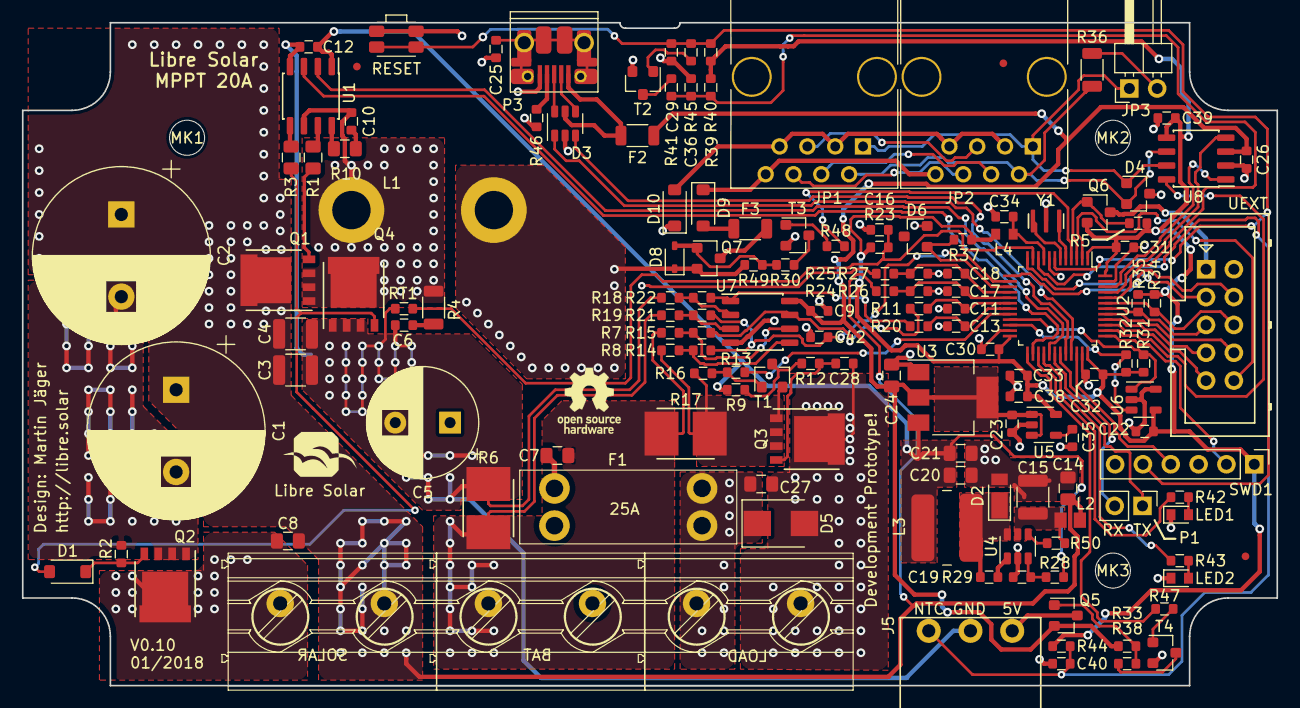
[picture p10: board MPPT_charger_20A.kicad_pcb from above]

Board: 2 copper layers, 114.5 x 60.5 mm, 146 parts (0 on the bottom side), 102 nets.

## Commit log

2016-06-05 Initial commit of schematic and board
    [MPPT_Charger_12A.brd, MPPT_Charger_12A.sch]
2016-06-05 PDF/PNG of schematic/board files uploaded
2016-06-05 Fixed clearance at some vias (DRC error)
    [MPPT_Charger_12A.brd]
2016-07-28 Foto of board uploaded
2016-12-13 Updated revision with 20A charge current
    [MPPT_Charger_12A.brd, MPPT_Charger_20A.brd, MPPT_Charger_20A.sch]
2016-12-17 Minor changes + nice image from Aisler.net
    [MPPT_Charger_20A.brd, MPPT_Charger_20A.sch]
2017-01-17 Fixing issues #12 and #11
    [MPPT_Charger_20A.brd, MPPT_Charger_20A.sch]
2017-03-22 Rev 0.7: moved to KiCAD
    [MPPT_Charger_20A.brd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]
2017-03-22 Removed temporary files from repository.
    [MPPT_charger_20A.csv]
2017-03-26 Updated R/C/L symbols to IEC 60617 style
    [MPPT_Charger_20A.sch, MPPT_charger_20A.kicad_pcb, dcdc.sch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]
2017-08-06 Updated revision: 0.8
    [MPPT_Charger_20A.sch, MPPT_charger_20A.kicad_pcb, MPPT_charger_20A.xlsx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]
2017-08-15 Minor changes and gerber export update
    [MPPT_charger_20A-B.Fab.gbr, MPPT_charger_20A-B.Mask.gbr, MPPT_charger_20A-B.Paste.gbr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]
2017-11-29 V0.8.1: Small changes and update to new kicad symbol library table (nightlies only)
    [MPPT_Charger_20A.sch, MPPT_charger_20A.kicad_pcb, analog_frontend.sch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]
2017-11-29 change of schematic to lowercase (_lowercase appended)
    [MPPT_Charger_20A_lowercase.sch]
2017-11-29 Change of schematic file name to lowercase
    [MPPT_charger_20A.sch]
2017-12-03 Bus power supply from battery instead of 10V rail
    [MPPT_charger_20A.kicad_pcb, MPPT_charger_20A.sch, interfaces.sch]
2017-12-11 Revision 0.9 for first small production batch - Switchable power supply for bus and UEXT (to be make sure to reach very low power consumption during LVD conditions) - MLCCs for EMC added to each high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
    [MPPT_charger_20A-B.Fab.gbr, MPPT_charger_20A-B.Mask.gbr, MPPT_charger_20A-B.Paste.gbr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]
2017-12-11 BOM updated
    [MPPT_charger_20A_bom.csv, mcu.sch]
2018-01-18 Final version for Jan/2018 production
    [MPPT_charger_20A-B.Fab.gbr, MPPT_charger_20A-B.Mask.gbr, MPPT_charger_20A-B.Paste.gbr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]
2018-01-26 Adjustments to use MP2459 as SMPS (previous one out of stock)
    [MPPT_charger_20A-B.Fab.gbr, MPPT_charger_20A-B.Mask.gbr, MPPT_charger_20A-B.Paste.gbr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]
2018-01-26 Power supply inductor changed to Tayo Yuden
    [MPPT_charger_20A_bom.csv, power_supply.sch]
2018-05-12 Update to KiCad 5 schematic library
    [MPPT_charger_20A.kicad_pcb, MPPT_charger_20A.sch, analog_frontend.sch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]
2018-05-12 BOM update
    [MPPT_charger_20A_bom.csv]
2019-10-05 Note regarding development of new version added
    [MPPT_charger_20A.sch]

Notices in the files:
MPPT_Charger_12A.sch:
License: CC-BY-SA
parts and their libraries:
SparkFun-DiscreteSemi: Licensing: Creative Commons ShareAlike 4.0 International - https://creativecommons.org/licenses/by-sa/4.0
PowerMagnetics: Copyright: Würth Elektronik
